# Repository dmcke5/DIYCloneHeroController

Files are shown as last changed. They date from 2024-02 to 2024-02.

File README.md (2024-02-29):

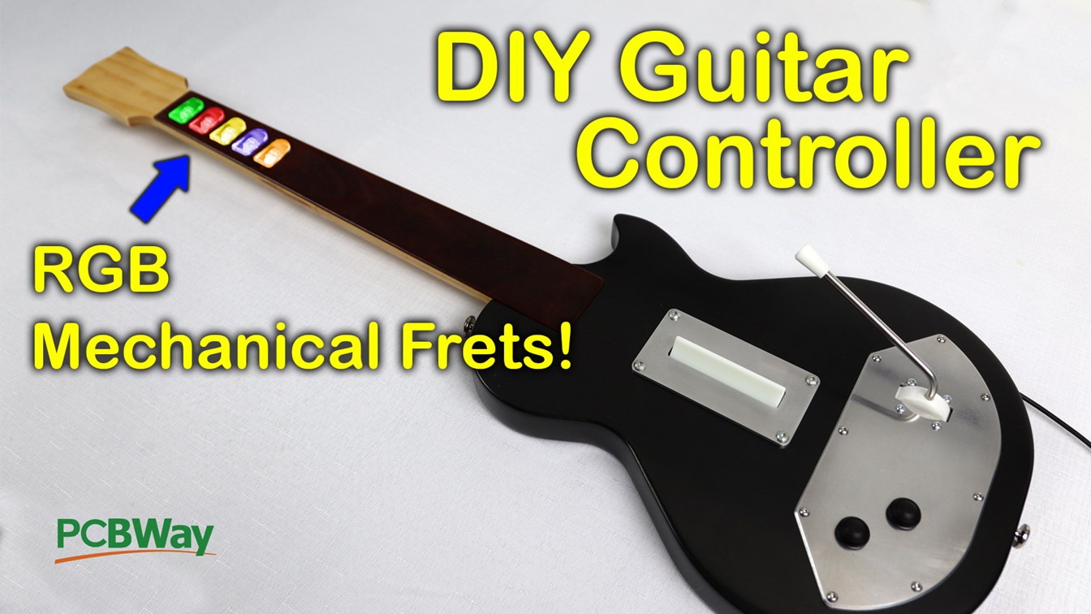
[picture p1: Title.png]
DIY Clone Hero Controller


# DIYCloneHeroController

Here's the printed version of my clone hero controller! 

#### Assembly
The original Youtube video should provide enough information for assembly, here's a link:

[The ULTIMATE DIY Clone Hero Controller](https://youtu.be/poKoy9RzIDI)

I've included 3mm holes between all of the printed body and kneck parts to help with alignment and strength when glueing them together for assembly.

#### Software
The Arduino code is pretty bare-bones, but its enough to get the controller functioning properly, it just doesn't have any fancy effects for the RGB lights, its just set up for a solid colour per button. There are other more feature rich softwares out there for diy guitar controllers so feel free to use one of those instead if you'd prefer. You may have to refer to their wiring diagram's for everything to work correctly though!

#### Wiring
Wiring for buttons is shown below on a Pro Micro Clone. You should be able to use the same pinout on any 32u4 based arduino. VCC and GND need to also be connected both to the Strum bar pcb and the
whammy bar potentiometer. The Strum bar PCB passes VCC and GND through to the neck PCB.
I used a 10k potentiometer for my whammy bar. The order that the buttons are connected in doesn't actually matter, as you'll configure them in clone hero anyway but if you stick to the pins I've specified you won't have to change the code. The LED signal is connected to pin 16.

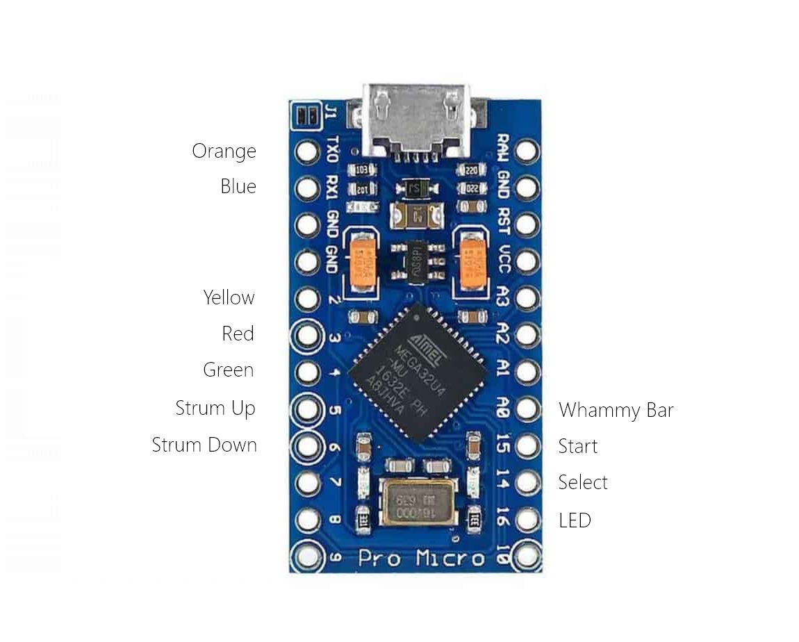
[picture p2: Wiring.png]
Wiring


#### PCB's
The neck and strum PCB's are designed to use a full sized mechanical keyboard switch. Any should work, but I used Gateron Blue's on mine since they were cheap and readily available to me.

If you're planning to use the RGB LED's you will also need:
- 10x 33ohm 0603 Resistors
- 5x WS2811 IC's
- 5x 0.1uf 0603 Capacitors
- 5x 100ohm 0603 Resistors
- 5x RGB LED's [Link](https://www.aliexpress.com/item/1005003719602946.html)

Please note on the neck PCB silk screen, one resistor on the orange fret is incorrectly labelled as a 0.1uf capacitor when it should be a 33ohm resistor. The components are in the same order on all 5 frets so just refer to the other fret buttons for the correct order.

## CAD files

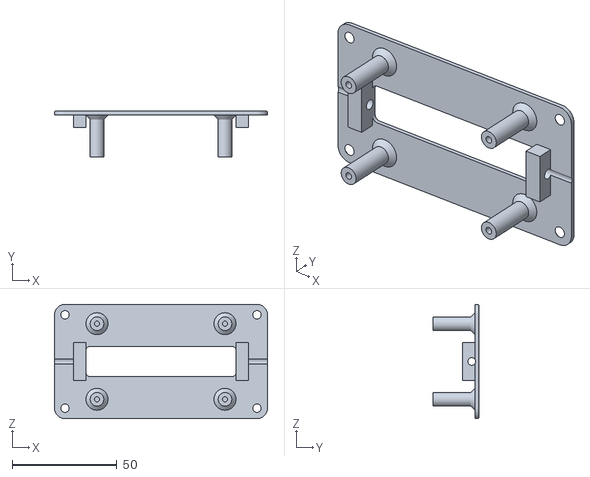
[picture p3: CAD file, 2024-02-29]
STL's/Strum Bar Mount Printed.STL
101.5 x 22.0 x 54.5

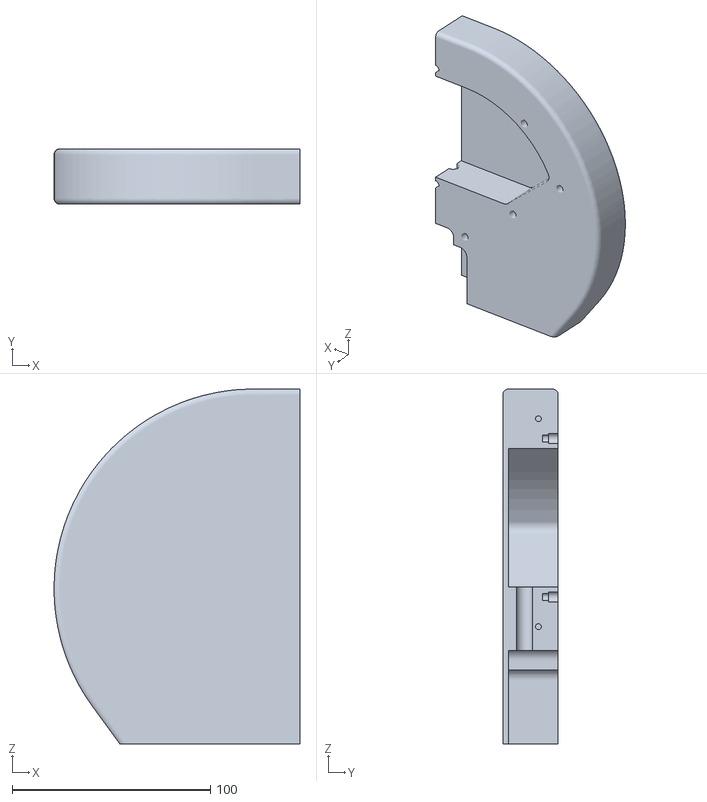
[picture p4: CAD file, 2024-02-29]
STL's/Les Paul Body Printed 2.STL
124.2 x 28.0 x 179.2

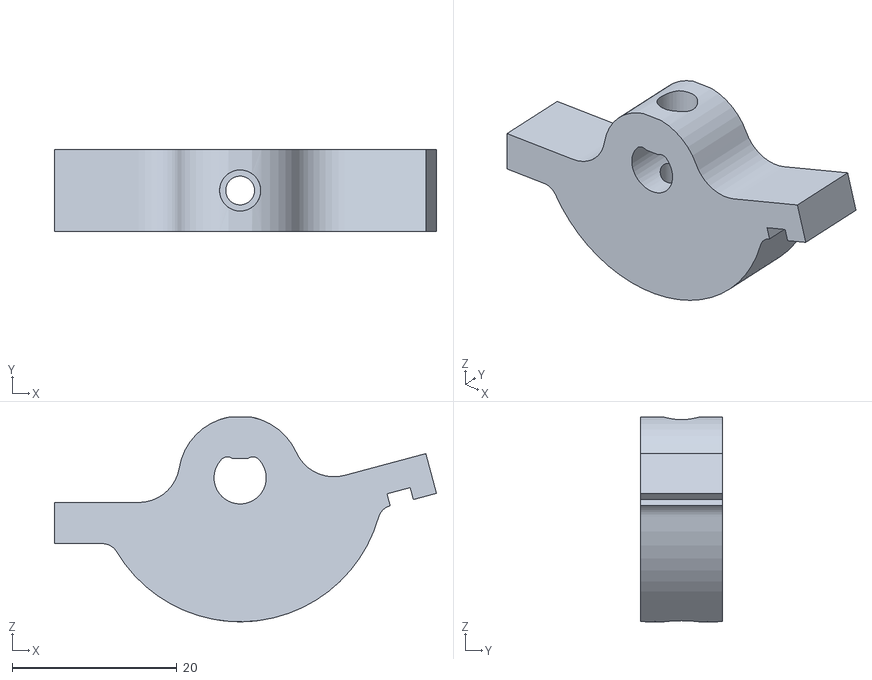
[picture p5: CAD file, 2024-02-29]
STL's/Whammy Bar Pivot.STL
46.4 x 10.0 x 24.9

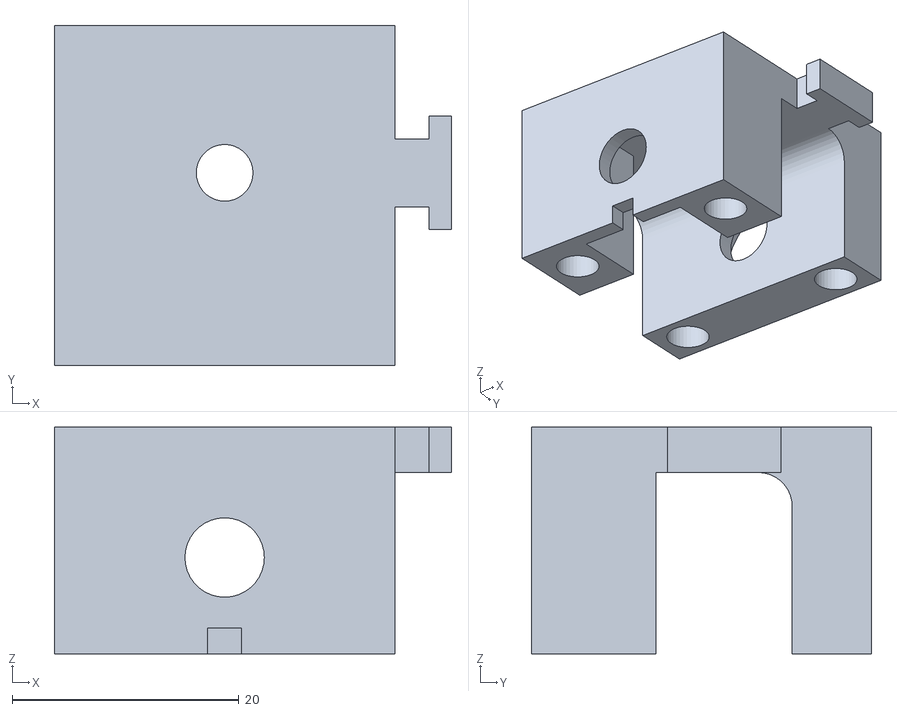
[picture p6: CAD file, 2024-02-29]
STL's/Potentiometer Mount.STL
35.0 x 30.0 x 20.0

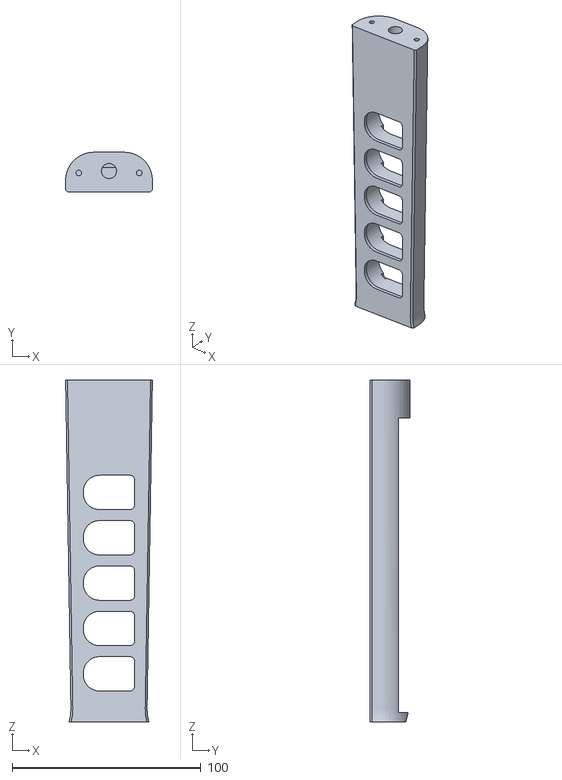
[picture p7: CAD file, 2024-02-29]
STL's/Les Paul Printed Kneck - Mid.STL
46.0 x 21.0 x 181.0

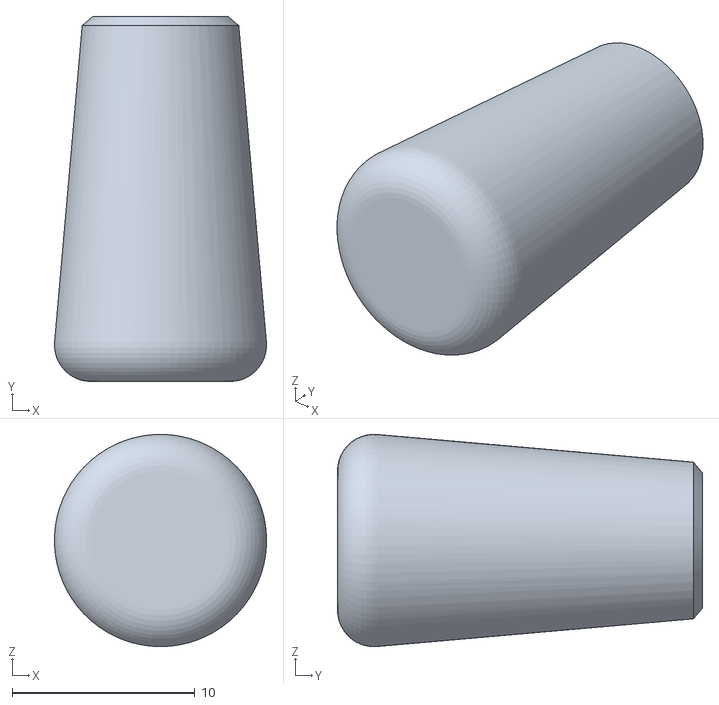
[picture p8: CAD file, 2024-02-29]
STL's/Whammy Bar Knob.STL
11.6 x 20.0 x 11.6

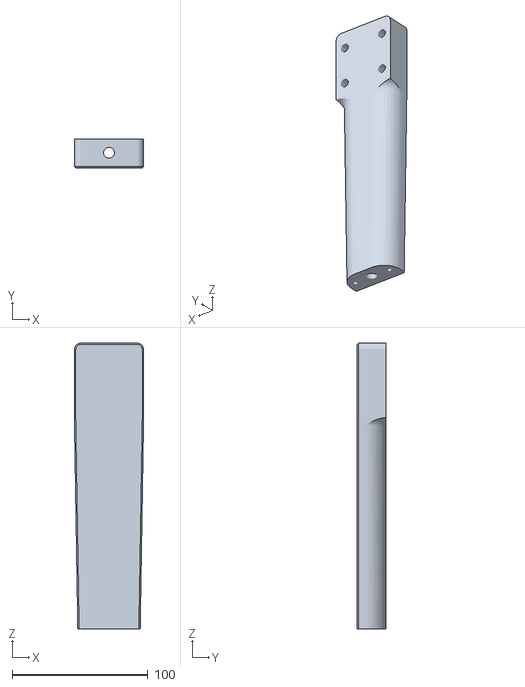
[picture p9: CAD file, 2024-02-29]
STL's/Les Paul Printed Kneck - Base.STL
51.0 x 21.0 x 210.5

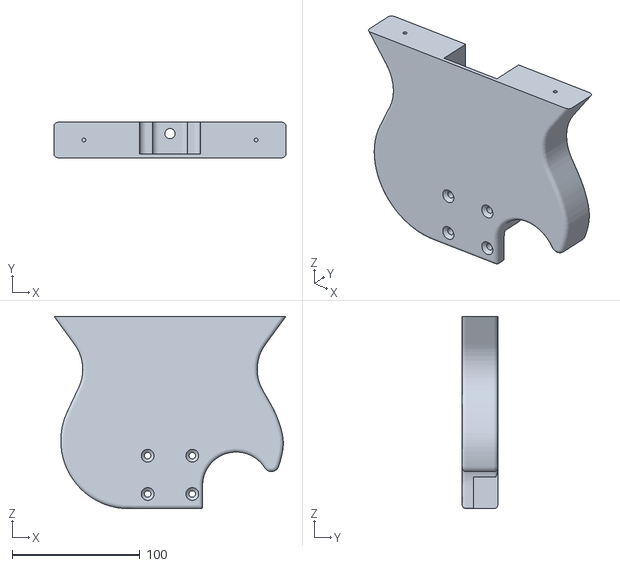
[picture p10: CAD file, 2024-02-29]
STL's/Les Paul Body Printed 3.STL
181.8 x 28.0 x 150.7

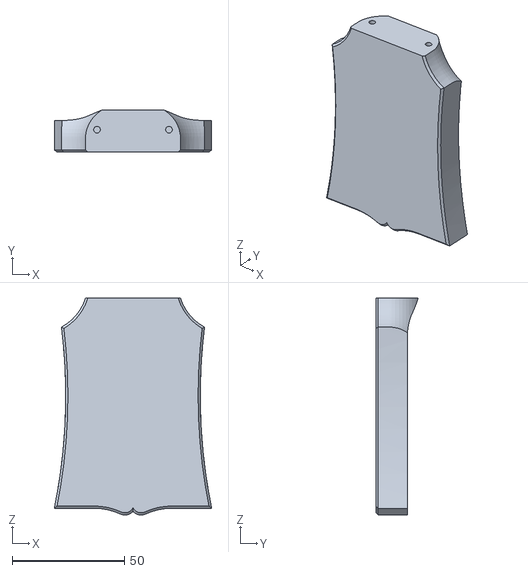
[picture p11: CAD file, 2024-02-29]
STL's/Les Paul Printed Kneck - Headstock.STL
70.0 x 18.9 x 96.5

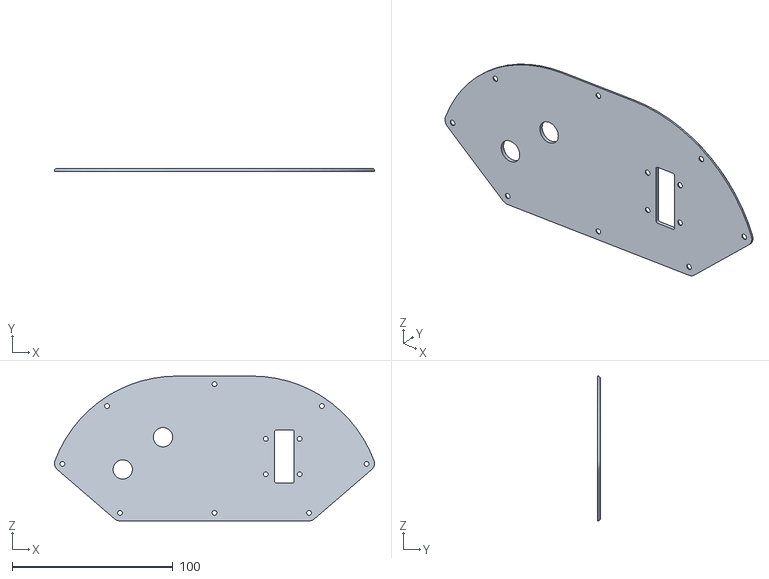
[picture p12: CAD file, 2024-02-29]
STL's/Whammy Mount Plate.STL
198.8 x 2.00 x 90.0

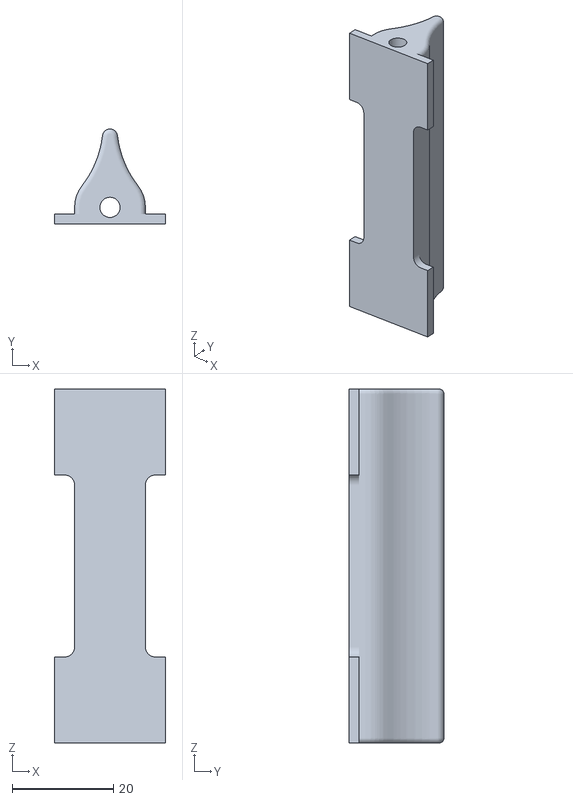
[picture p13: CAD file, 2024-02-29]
STL's/Strum Bar.STL
22.0 x 18.8 x 70.0

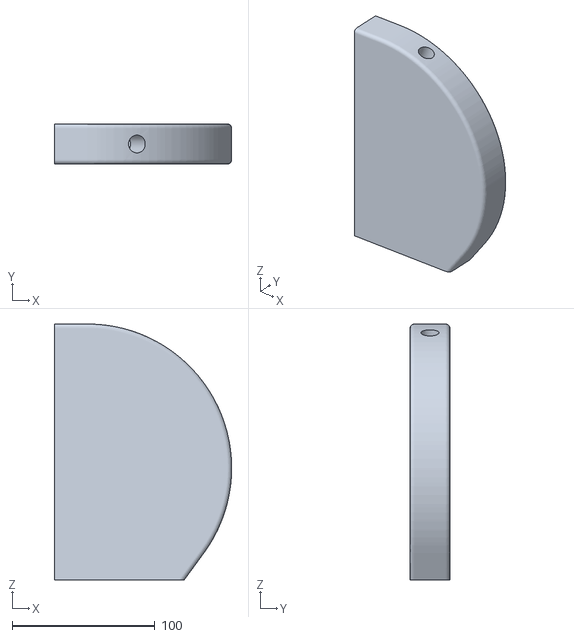
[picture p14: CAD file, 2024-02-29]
STL's/Les Paul Body Printed 1.STL
124.2 x 28.0 x 179.2

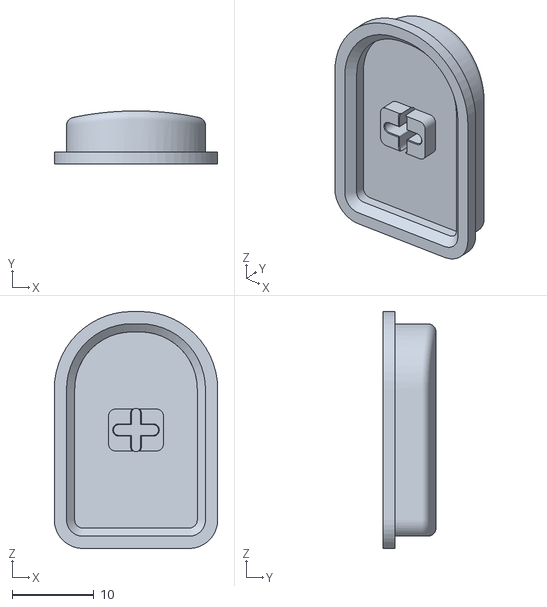
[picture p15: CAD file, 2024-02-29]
STL's/Fret Button.STL
20.0 x 6.50 x 29.0

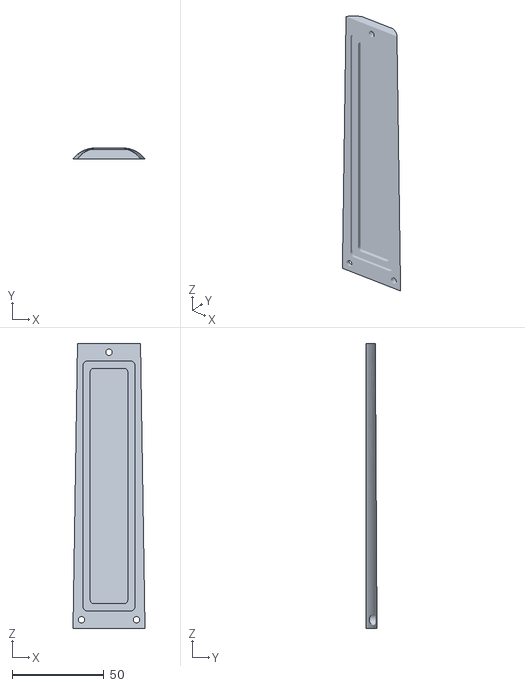
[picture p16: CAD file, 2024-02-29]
STL's/Les Paul Printed Kneck - PCB Cover.STL
39.3 x 6.00 x 155.6

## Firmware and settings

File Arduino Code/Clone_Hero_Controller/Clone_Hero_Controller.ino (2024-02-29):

#include <Joystick.h> //https://github.com/MHeironimus/ArduinoJoystickLibrary
#define baudrate 19200 //Baudrate for serial.
#include <FastLED.h>

//Define button pins
byte buttonCount = 9; //Number of buttons in use. Change length of buttonPins, lastButtonState and currentButtonState to match.
byte buttonPins[9] = {0,1,2,3,4,5,6,15,14}; //Array to store digital pins used for buttons. Length must be the same as buttonCount.

//Button state arrays
byte lastButtonState[9]; //Empty State array for buttons last sent state. Must be same length as buttonPins
byte currentButtonState[9]; //Empty State array for buttons. MMust be same length as buttonPins

//Whammy bar config
const int whammyBar = A0;
const int deadBand = 25;
const int whammyMin = 140; //Adjust for Minimum whammy bar endpoint
const int whammyMax = 250; //Adjust for Max whammy bar endpoint

//Main Joystick setup
Joystick_ Joystick(JOYSTICK_DEFAULT_REPORT_ID,JOYSTICK_TYPE_GAMEPAD,
buttonCount, 0,       // Button Count, Hat Switch Count
false, false, true,     // X Y Z
false, false, false,  // Rx, Ry, Rz
false, false,          // Rudder, Throttle
false, false, false); // Accelerator, Brake, Steering

//LED Settings
#define LED_PIN     16
#define NUM_LEDS    5
CRGB leds[NUM_LEDS];

void setup() {
  FastLED.addLeds<WS2811, LED_PIN, RGB>(leds, NUM_LEDS);
  Joystick.setZAxisRange(0, 254);
  Joystick.begin(false); //Initialise joystick mode with auto sendState disabled.
  for(int i = 0; i < buttonCount; i++){ //Set all button pins as input pullup. Change to INPUT if using external resistors.
    pinMode(buttonPins[i], INPUT_PULLUP);
  }
  leds[0] = CRGB::Orange;
  leds[1] = CRGB::Blue;
  leds[2] = CRGB::Yellow;
  leds[3] = CRGB::Red;
  leds[4] = CRGB::Green;
  FastLED.show();
}

void loop() {
  buttonRead();
  joypadButtons();
  int temp = analogRead(whammyBar);
  if(temp > whammyMin + deadBand){
    temp = map(temp, whammyMin, whammyMax, 0, 254);
    Joystick.setZAxis(temp);
  } else {
    Joystick.setZAxis(0);
  }
  Joystick.sendState();
}

void buttonRead(){ //Read button inputs and set state arrays.
  for (int i = 0; i < buttonCount; i++){
    int input = !digitalRead(buttonPins[i]);
    if (input != lastButtonState[i]){
      lastButtonState[i] = input;
    }
  }
}
void joypadButtons(){ //Set joystick buttons for USB output
  for(int i = 0; i < buttonCount; i++){
    if(lastButtonState[i] != currentButtonState[i]){
      Joystick.setButton(i, lastButtonState[i]);
      currentButtonState[i] = lastButtonState[i];
    }
  }
}
